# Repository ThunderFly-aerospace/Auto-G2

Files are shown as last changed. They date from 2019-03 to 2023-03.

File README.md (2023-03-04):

# Auto-G2 - Small gyroplane model
The design is based on [Auto-G2 by Durafly](https://hobbyking.com/en_us/duraflytm-auto-g2-gyrocopter-w-auto-start-system-821mm-pnf.html) which is extended by [PX4 autopilot](https://en.wikipedia.org/wiki/PX4_autopilot). The Auto-G2 model is discontinued and is not longer available. 
Adequate substitute is the [3D printed TF-G2 autogyro kit](https://github.com/ThunderFly-aerospace/TF-G2). 

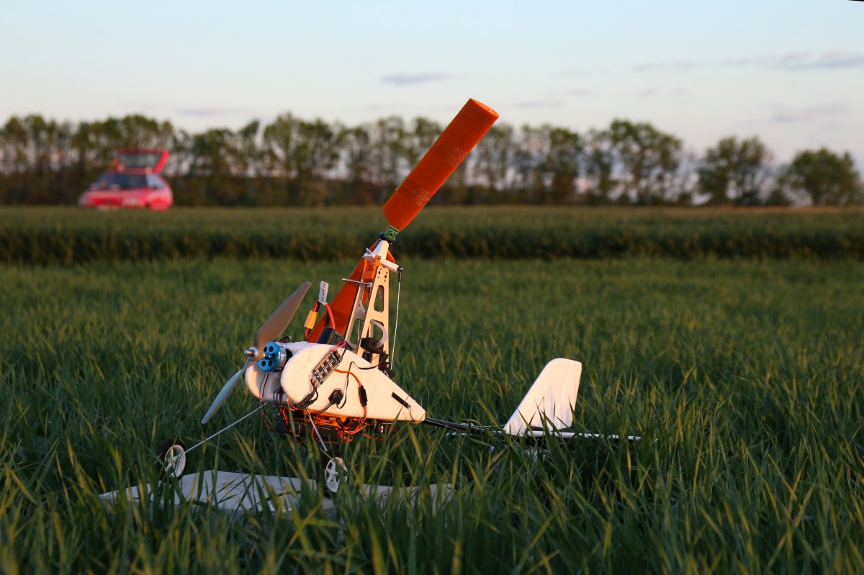
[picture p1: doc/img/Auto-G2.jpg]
Auto-G2 autogyro


The original purpose of this model is the training and testing of PX4 software improvements, prior the autogyro airframe has been sucessfully merged to [PX4 airframes](https://docs.px4.io/main/en/airframes/airframe_reference.html#autogyro).

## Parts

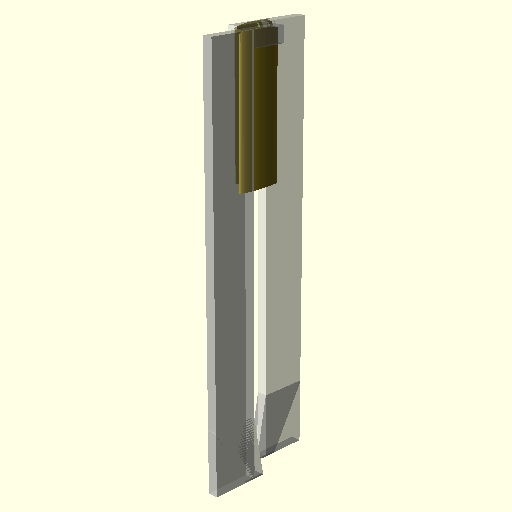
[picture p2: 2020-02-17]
CAD/img/print_plate_111_1009_parts_tips.png

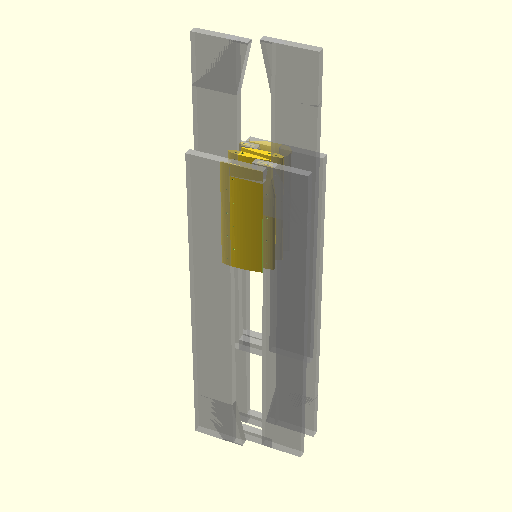
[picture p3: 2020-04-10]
CAD/img/print_plate_111_1009_parts.png

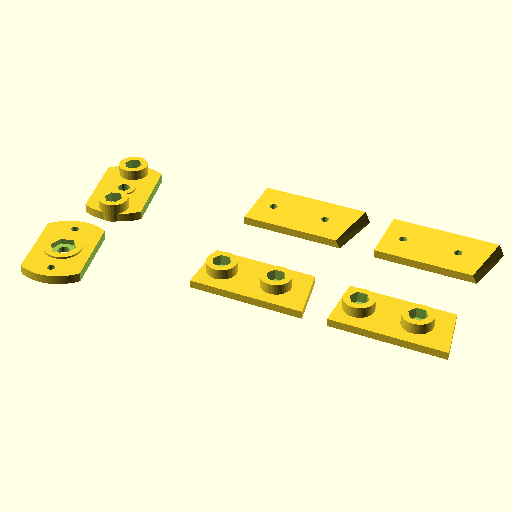
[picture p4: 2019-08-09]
doc/img/print_plate_rotor_parts.png

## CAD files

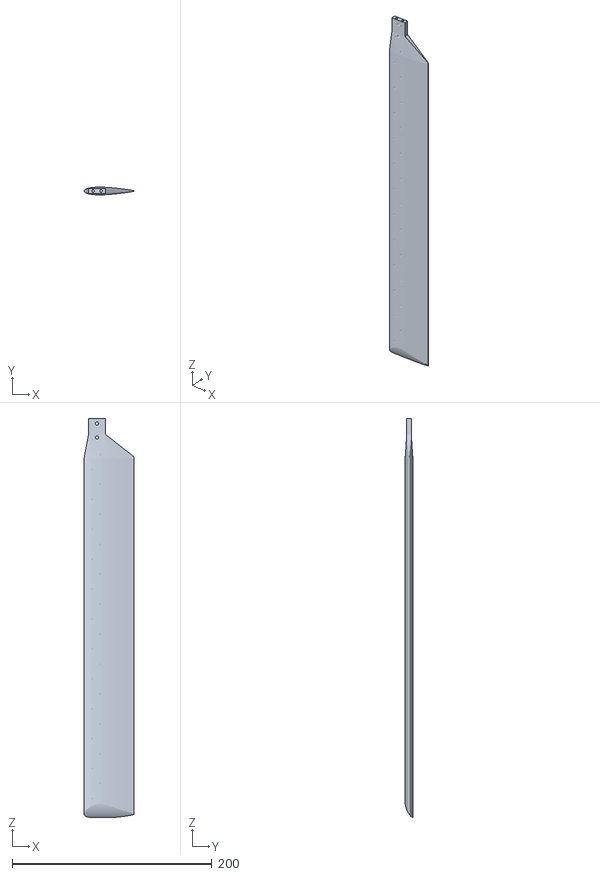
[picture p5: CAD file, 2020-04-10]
CAD/stl/111_1009.stl
50.0 x 7.80 x 400.0

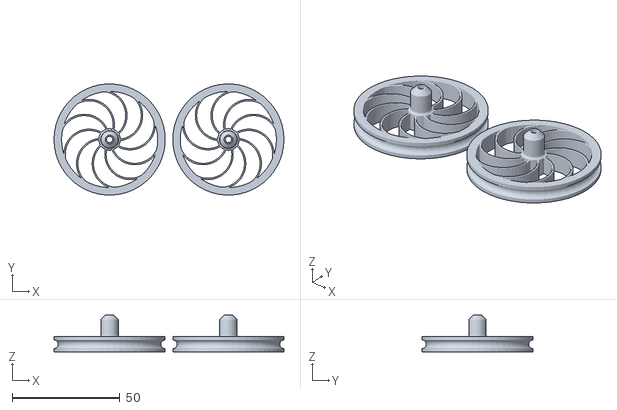
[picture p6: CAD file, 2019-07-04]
CAD/stl/manufacturing_helpers/print_plate_888_1011.stl
106.5 x 51.4 x 17.0

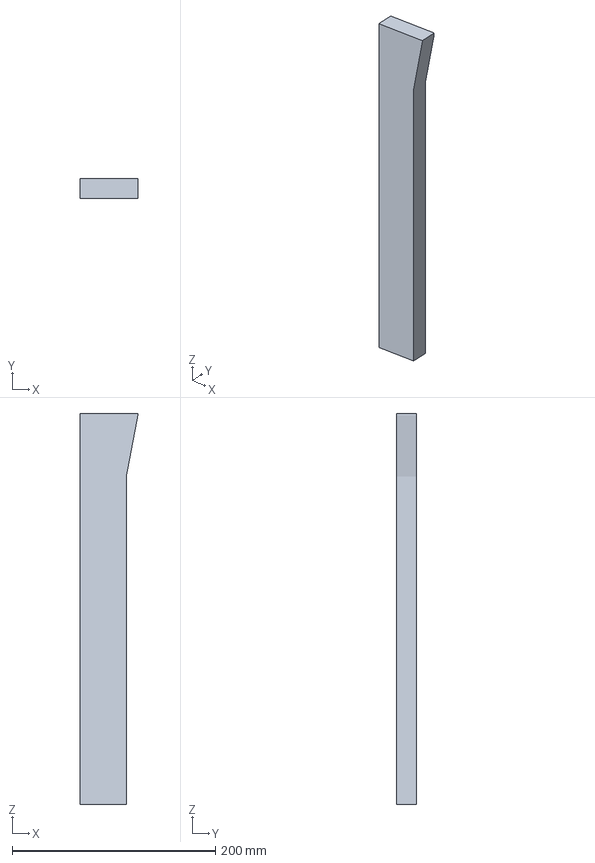
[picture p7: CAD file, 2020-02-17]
CAD/amf/111_1009_111_1009_modificator.amf
56.9 x 20.0 x 385.0 mm

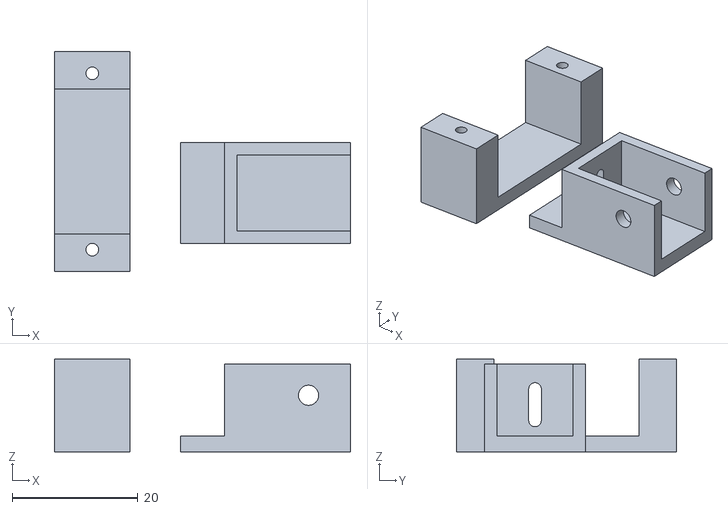
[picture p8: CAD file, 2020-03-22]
CAD/stl/888_1010.stl
47.0 x 35.0 x 14.8

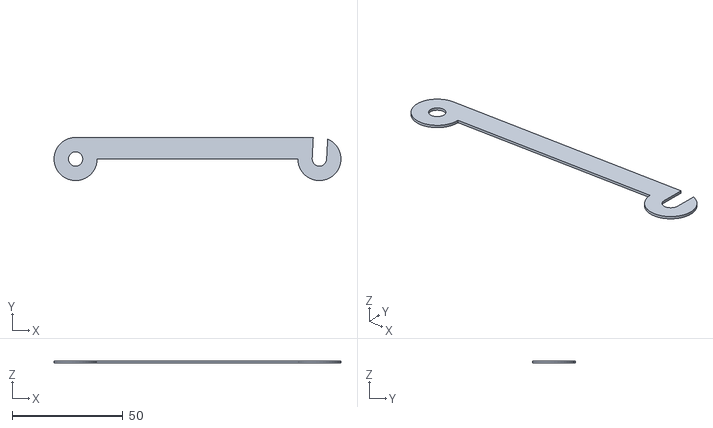
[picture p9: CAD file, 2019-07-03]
CAD/stl/manufacturing_helpers/print_plate_888_1009_scale.stl
129.5 x 19.5 x 1.00

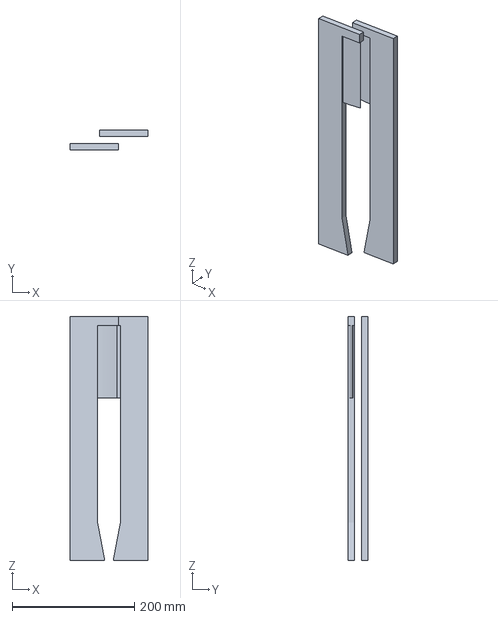
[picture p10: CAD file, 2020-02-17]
CAD/amf/print_plate_111_1009_parts_tips.amf
128.2 x 32.0 x 400.0 mm

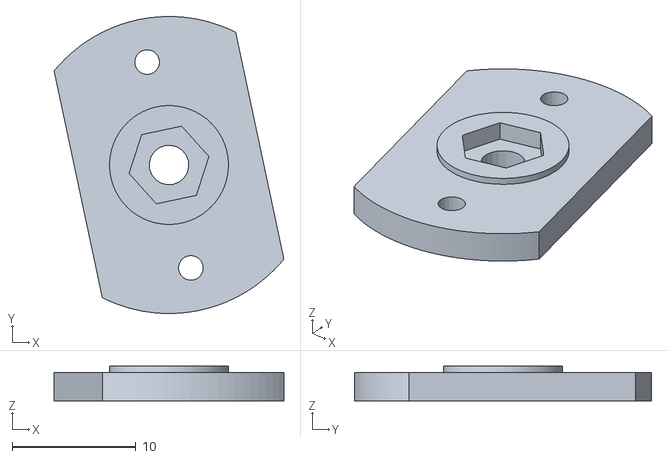
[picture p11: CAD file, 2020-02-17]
CAD/stl/111_1004.stl
18.6 x 24.0 x 2.80

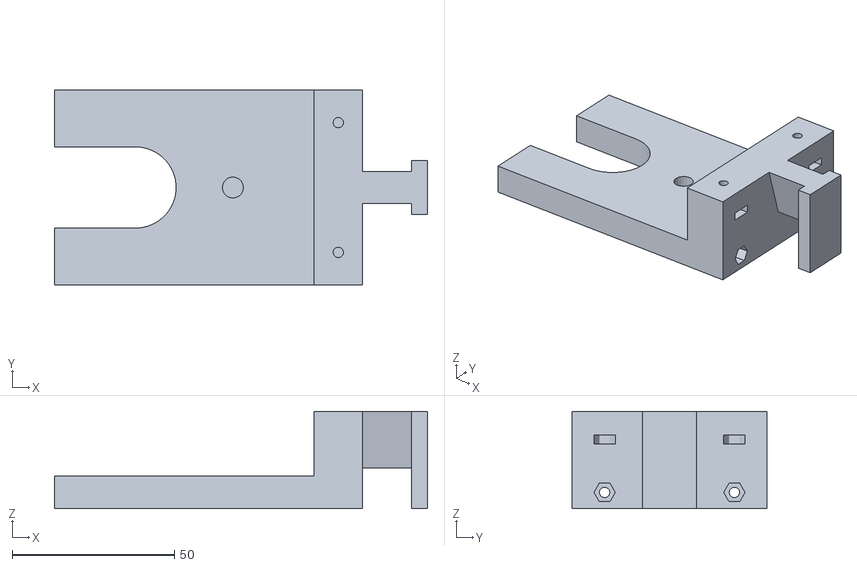
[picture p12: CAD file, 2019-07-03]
CAD/stl/manufacturing_helpers/print_plate_888_1009_cradle.stl
115.0 x 60.0 x 30.0

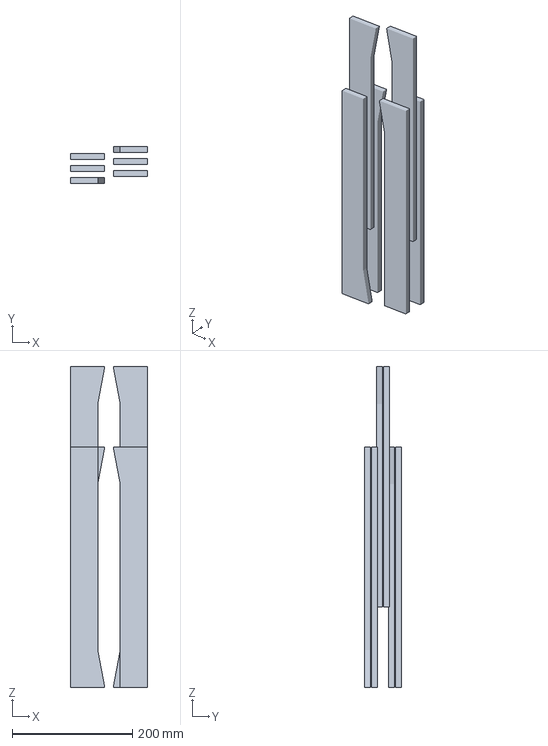
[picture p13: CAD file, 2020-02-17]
CAD/amf/print_plate_111_1009_parts_modificator.amf
128.2 x 62.0 x 533.3 mm

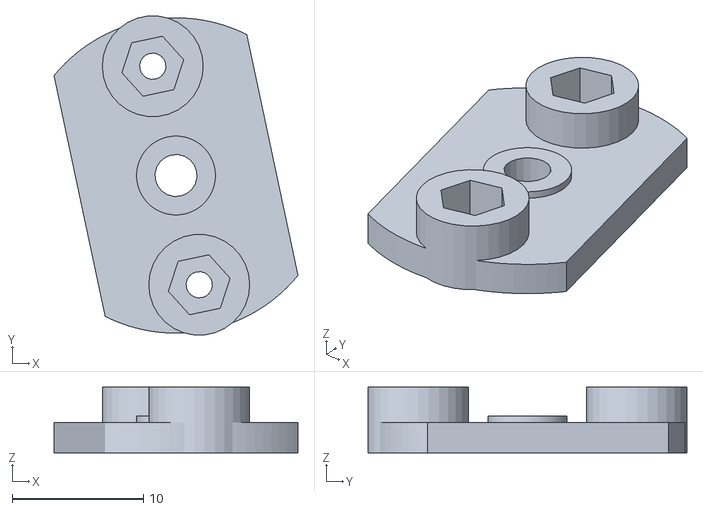
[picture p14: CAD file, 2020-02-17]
CAD/stl/111_1008.stl
18.6 x 24.3 x 5.00

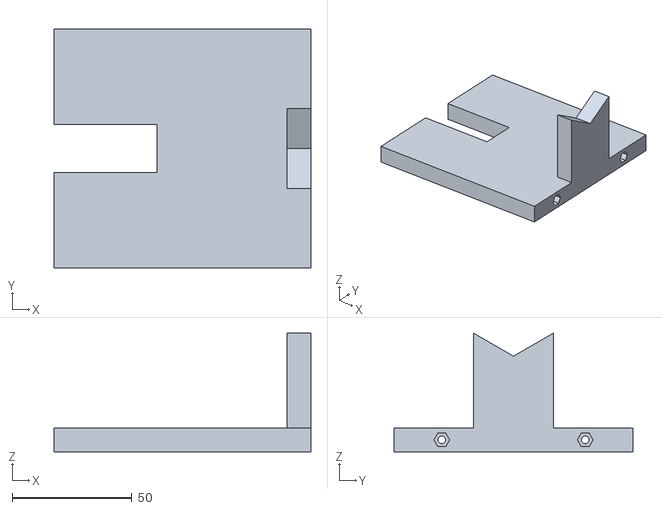
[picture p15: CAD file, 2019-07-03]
CAD/stl/manufacturing_helpers/print_plate_888_1009_base.stl
107.5 x 100.0 x 49.6

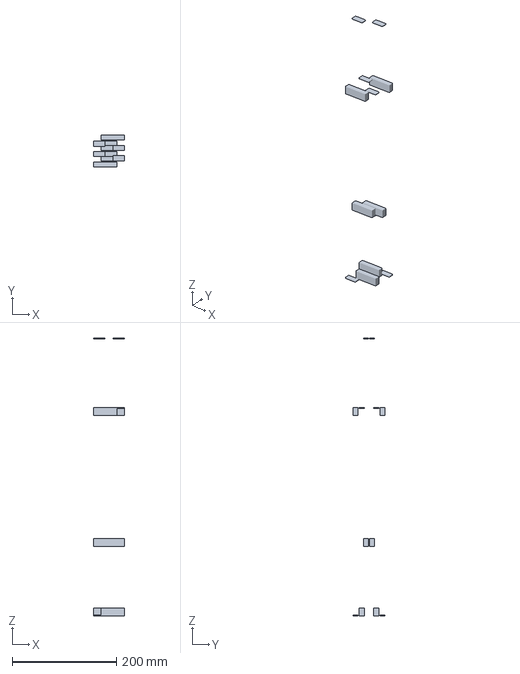
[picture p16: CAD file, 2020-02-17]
CAD/amf/print_plate_111_1009_parts_modificatorb.amf
60.0 x 62.0 x 533.3 mm

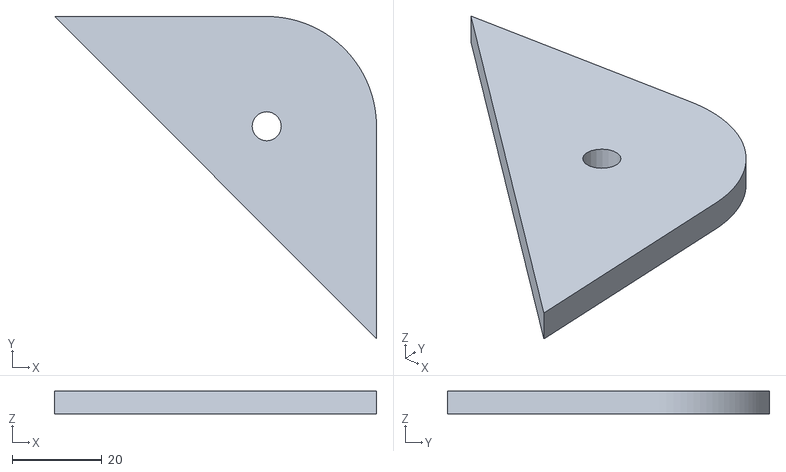
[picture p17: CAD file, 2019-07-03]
CAD/stl/manufacturing_helpers/print_plate_888_1009_shapeA.stl
71.8 x 71.8 x 5.10

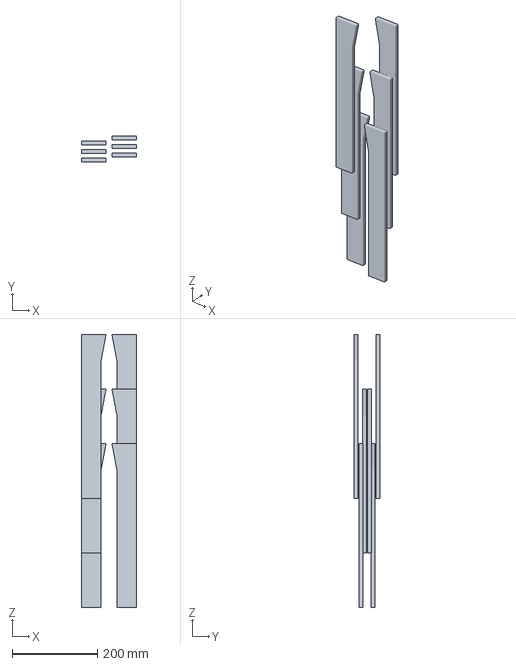
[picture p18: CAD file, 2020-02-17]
CAD/amf/print_plate_blades_parts_modificator.amf
128.2 x 62.0 x 641.7 mm

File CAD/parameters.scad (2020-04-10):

global_clearance = 0.5;
layer_thickness = 0.3;

//Main tube diameter - hole [mm]
main_tube_outer_diameter = 25.4;
main_tube_inner_diameter = 23.05;

// Nastavení parametrů rotoru

gliding_aggle = 14;         // tenhle úhel by se zřejmě v budoucnu měl počítat z požadované klouzavosti.

rotor_blade_AOA = 3.5;      // nastavení úhlu náběhu rotorového listu

// Rotor Auto-G2
rotor_blade_rod = true;  // generovat diru pro uhlikove tycky
rotor_blade_length = 400;   // délka rotorového listu
rotor_blade_depth = 52;     // hloubka rotorového listu
rotor_balde_tip_cutoff = 15; // delka sikme plochy na konci listu

blade_mount_length = 30;

blade_mount_width = 17;
blade_mount_thickness = 4.6;
blade_mount_screw_offset = 5; // distance of first screw from rotor end

// Testovaci maly rotor

        /*
        rotor_blade_rod = false;
        rotor_blade_length = 145;   // délka rotorového listu
        rotor_blade_depth = 45.5 * (145/385);     // hloubka rotorového listu
        blade_mount_length = 20;
        blade_mount_width = 10;
        blade_mount_thickness = 4;
        */

// konec parametru pro testovaci maly rotor

rotor_height = 180;         // výška otočného kloubu rotoru nad hlavní trubkou vírníku (odhad)
rotor_blades_count = 2;
rotor_delta_angle = 12;
rotor_blade_thickness = 5.1;

rotor_blade_naca = 0015;
//rotor_blade_naca = 1214;
rotor_blade_parts_count = 3;

blade_transition_length = 10; // length of blade transition

blade_mount_screw_distance = (16.47+11.86)/2;

/* blade_shell_thickness = 0.4;
blade_shell_thickness_inner = 0.4;
blade_shell_thickness_wire = 0.4;
blade_infill_distance = 25;
blade_infill_overlap = 0; */

/// Nastaveni pro Slic3r
blade_shell_thickness = 0.6;
blade_shell_thickness_inner = 0.13;
blade_shell_thickness_wire = 0.55;
blade_infill_distance = 30;
blade_infill_overlap = 0;


//blade_rod_position = [rotor_blade_depth/4 + 5, 0, 0];
//blade_rod_position2 = [rotor_blade_depth/4 - 5, 0, 0];

//blade_rod_position = [15, 0, 0];
//blade_rod_position2 = [4, 0.3, 0];

blade_rod1_diameter = 0.2;
blade_rod2_diameter = 2.58;
blade_rod3_diameter = 2.13;

blade_rod2_diameter = 2.58;
blade_rod3_diameter = 2.58;

blade_rod1_position = [3.65, 0, 0];
blade_rod2_position = [rotor_blade_depth/4 - 4, 0, 0];
blade_rod3_position = [rotor_blade_depth/4 + 4, 0, 0];

rod_from_end = 9;

rotor_head_width =  21.4;    //Rozměr 1 v nákresu
pilon_wall_thickness = 4.2;  // Rozměr 2 v nákresu
horizontal_screw_distance = 14.5;   // Rozměr 4 v nákresu
vertical_screw_distance = 12;       // rozměr 5 v nkresu
topscrew_distance_endofpilon = 5;

rotorhead_wall_thickness = 2; // sila tistenych dilu


bearing_outer_diameter = 10.2;    // Rozměr B1 v nákresu s přídavkem na toleranci otvoru
bearing_thickness = 4;        // Rozměr B2 v nákresu
//bearing_shaft_length = 19.5;    // Rozměr B3 v nákresu, Originalni hodnota 19.5
bearing_shaft_length = 20;    // Rozměr B3 v nákresu


// nastavení parametrů motoru

engine_angle = -8;
engine_diameter = 55;
engine_offset = 55;

engine_screws_radius = 15;
engine_holes_radius = (24 + 44)/4;
engine_shatf_hole_diameter = 13;

// screw length step - minimum difference in length between two types of screws
basic_screw_length = 5;

//Screw diameter and nut for M6 [mm]
M6_screw_diameter=6.5;
M6_head_diameter = 10+0.5;
M6_head_height = 6;
M6_nut_height = 4.9;
M6_nut_diameter = 11.8;
M6_nut_pocket = 10.4;

//Screw diameter and nut for M5 [mm]
M5_screw_diameter=5.5;
M5_head_height = 5;
M5_head_diameter = 13+0.5;
M5_nut_height = 4.5;
M5_nut_diameter = 9.4;
M5_nut_pocket = 8.4;

//Screw diameter and nut for M4 [mm]
M4_screw_diameter=4.5;
M4_screw_head_height = 4;
M4_nut_height = 3.2;
M4_nut_diameter = 8.4;
M4_nut_pocket = 7.5;

//Screw diameter and nut for M3 [mm]
M3_screw_diameter = 3.2;
M3_nut_height = 2.7;
M3_nut_diameter = 6.6;
M3_screw_head_height = 3;
M3_nut_pocket = 5.6;


//Screw diameter and nut for M2,5 [mm]
M2_5_screw_diameter = 2.7;
M2_5_nut_height = 2.3;
M2_5_nut_diameter = 6;
M2_5_nut_pocket = 5.1;

//Screw diameter and nut for M2 [mm]
M2_screw_diameter = 2.0;
M2_nut_height = 1.8;
M2_nut_diameter = 4.8;
M2_nut_pocket = 3.95;


blade_mount_screw = M3_screw_diameter;
blade_mount_nut = M3_nut_diameter;


//šroub servo
Servo_screw = 1.5;
Servo_nut_height = 1;
Servo_nut_diameter = 2.7;



//center_of_gravity_position = [main_pilon_position - tan(gliding_aggle)*rotor_height, 0, 0];


////podzvozek

radius_undercarriage = 25;
vzdalenost_x = tan(20) * 131;
vzdalenost_y = (131 - radius_undercarriage)/tan(79);
uhel_y = 90 - 20;
uhel_x = 90 - 79;

maximum_printable_size = 150;


////Pitotova trubice
Pitot_tube_diameter = 4.02 + 1;
Distance_hole_from_tube = 11.92;  //vzdálenost otvoru pro připevnění od samotné trubičky


////Vlečné zařízení
tow_ring_diameter = 20;
tow_ring_thickness = 5;
tow_ring_groove = 2;
tow_ring_hole_diameter = M3_screw_diameter;

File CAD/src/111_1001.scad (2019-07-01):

//// ThunderFly Auto-G2 Rotor Head - Part 1

/// Main parameters

include <../parameters.scad>

L1 = rotor_head_width;  // Length of the middle part
T1 = rotorhead_wall_thickness;  // Thickness of the middle wall
T2 = rotorhead_wall_thickness;  // Thickness of the side walls
H = 23;  // Hight of the part
L2 = 28;  // Length of the side walls

/// Parameters for holes
RC = M3_screw_diameter/2;  // Radius of the center screw holes
RP = M2_screw_diameter/2;  // Radius of the periphery screw holes
DY = horizontal_screw_distance;  // Y-axis distance of the periphery screw holes
DZ = vertical_screw_distance;  // Z-axis distance of the periphery screw holes

shift =  - 15;
CHT = [0, shift, -20];  // Center hole translation

fn = 100;  // default face number for cylinders
/// Main object

module body() {
    translate([0,-T1/2, 0]) difference() {
        union(){
            translate([0, 0, 0])
                cube([L1, L2, H], center= true);
            hull(){
                translate([0, -L2/4, -vertical_screw_distance/2 - topscrew_distance_endofpilon])
                    cube([L1, L2/2, 0.1], center= true);
                translate(CHT+[0, T1/2, 0])
                    rotate([0,90,0])
                        cylinder(r=RC+2, h=L1+4, center = true, $fn=fn);

            }


            hull(){
                translate([0, 0, 0])
                    cube([L1, L2, H-6], center= true);
                translate(CHT+[0, 6, 7])
                    rotate([0,90,0])
                        cylinder(r=RC+2, h=L1, center = true, $fn=fn);

            }

        }

        cube([L1-2*T2, L2-2*T1, H*10], center = true);

        translate([0,0,-50])
            cube([L1-2*T2, 50, 100], center = true);
    }

}



/// Part 1 with holes and incisions
module Part1(){
    translate(-CHT){
        difference(){
        body();
           // Screw holes
            translate(CHT) rotate([0,90,0]) cylinder(r=RC, h=L1+10, center = true, $fn=fn);
            rotate([0,90,0]) translate([DZ/2,DY/2,0]) cylinder(r=RP, h=L1+2, center = true, $fn=fn);
            rotate([0,90,0]) translate([-DZ/2,DY/2,0]) cylinder(r=RP, h=L1+2, center = true, $fn=fn);
            rotate([0,90,0]) translate([DZ/2,-DY/2,0]) cylinder(r=RP, h=L1+2, center = true, $fn=fn);
            rotate([0,90,0]) translate([-DZ/2,-DY/2,0]) cylinder(r=RP, h=L1+2, center = true, $fn=fn);

           // Zapusteni pro matky
            rotate([0,90,0]) translate([DZ/2,DY/2,0]) cylinder(d=M2_nut_diameter, h=L1-2*T2+1, center = true, $fn=6);
            rotate([0,90,0]) translate([-DZ/2,DY/2,0]) cylinder(d=M2_nut_diameter, h=L1-2*T2+1, center = true, $fn=6);
            rotate([0,90,0]) translate([DZ/2,-DY/2,0]) cylinder(d=M2_nut_diameter, h=L1-2*T2+1, center = true, $fn=6);
            rotate([0,90,0]) translate([-DZ/2,-DY/2,0]) cylinder(d=M2_nut_diameter, h=L1-2*T2+1, center = true, $fn=6);
        }
    }
}

Part1();

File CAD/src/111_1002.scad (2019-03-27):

//// ThunderFly - Rotor Head - Part 2

include <../parameters.scad>

length = rotor_head_width-2*rotorhead_wall_thickness-0.15; // Length of the part
axis_diameter = M3_screw_diameter;
space = 1; // Axis hole distance
wall = 1;

add = 5; // prodlouzeni osy ve smeru roll osy

$fn = 100;

module Part2(){
  translate([0, 0, -wall-axis_diameter/2])
    difference(){
        hull(){
            translate([-length/2, -(axis_diameter + 2*wall)/2, 0])
                cube([length, axis_diameter + 2*wall, axis_diameter + 2*wall + add]);
            translate([0, axis_diameter + space, 0])
                cylinder(d = axis_diameter + 2*wall, h = axis_diameter + 2*wall + add);
        }
    translate([0, axis_diameter + space, -0.1])
        cylinder(d = axis_diameter, h = 100);
    rotate([0, 90, 0])
        translate([-(axis_diameter + 2*wall)/2, 0, -50])
            cylinder(h = 100, d = axis_diameter);
    }
}

Part2();

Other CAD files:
CAD/amf/print_plate_rotor_parts.stl
CAD/stl/print_plate_888_1011.stl
CAD/stl/manufacturing_helpers/print_plate_888_1009_shapeB.stl
CAD/stl/print_plate_888_1001.stl
CAD/src/111_1003.scad
CAD/STL/111_1009_parts.stl
CAD/STL/111_1102.stl
CAD/amf/111_1002.amf
CAD/amf/111_1009.amf
CAD/amf/888_1010.amf
CAD/amf/print_plate_rotor_parts.amf
CAD/src/111_1004.scad
CAD/src/111_1005.scad
CAD/src/111_1006.scad
CAD/src/111_1007.scad
CAD/src/111_1008.scad
CAD/src/111_1009.scad
CAD/src/111_1101.scad
CAD/src/111_1102.scad
CAD/src/4printing/print_plate_111_1009_parts.scad
CAD/src/4printing/print_plate_111_1009_parts_tips.scad
CAD/src/4printing/print_plate_888_1001.scad
CAD/src/4printing/print_plate_888_1011.scad
CAD/src/4printing/print_plate_rotor_parts.scad
CAD/src/888_1001.scad
CAD/src/888_1002.scad
CAD/src/888_1003.scad
CAD/src/888_1010.scad
CAD/src/888_1011.scad
CAD/stl/111_1001.stl
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

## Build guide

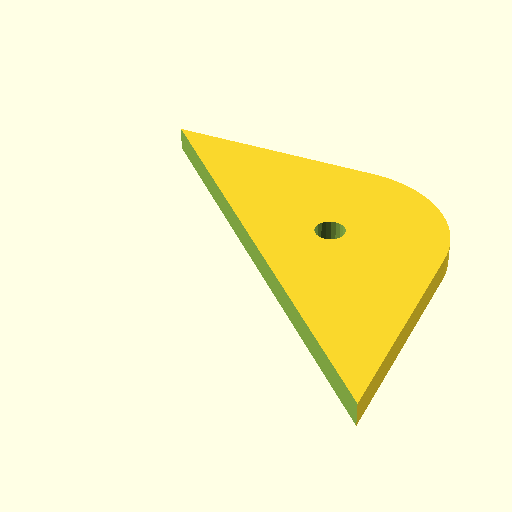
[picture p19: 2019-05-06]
doc/img/print_plate_1009_shapeA.png

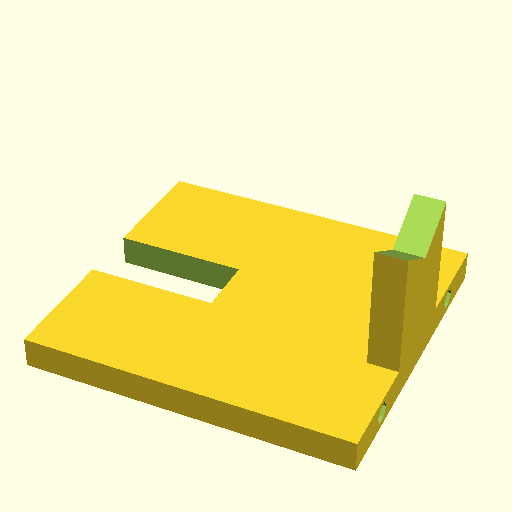
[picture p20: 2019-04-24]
doc/img/print_plate_1009_base.png

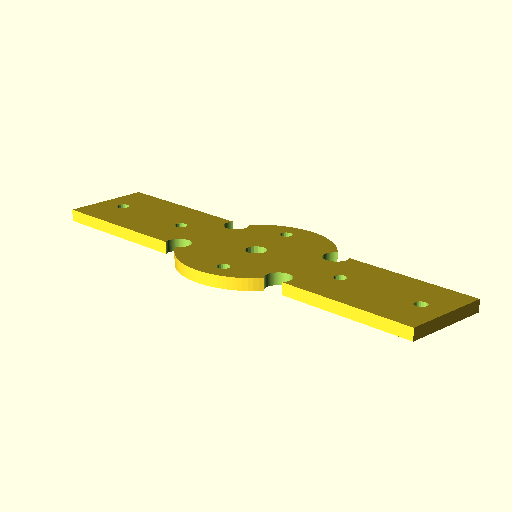
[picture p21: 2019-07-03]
doc/img/print_plate_888_1001_4.png

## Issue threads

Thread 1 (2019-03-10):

Rotorová hlava umožňující řízení roll i pitch os

roman-dvorak, 2019-03-10:
Je potřeba namodelovat rotorová hlava pro Auto-G2 napodobující fungování rotorové hlavy vírníku TF-G1.

Rotorová hlava musí umožňovat změnu výchylek v osách pitch a roll.

Modely je potřeba modelovat parametricky, aby bylo možné snadno změnit jejich rozměry. Rozměry, které jsou napsané tužkou jsou jen odhadnuté. @kaklik je přeměří a upřesní.

Na tomto obrázku je vidět, kde tyto modely budou umístěny. Půjde o nahrazení originálních dílů umístěných přímo pod rotorem.

## Díl 1
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

První díl slouží k udržení konstantní vzdálenosti dvou dřevěných postranních částí pilonu a zároveň je v něm umístěna osa okolo které se otáčí ```Díl 2```. Tento díl je k postranním deskám přidělán pomocí dvou čtveřic šroubků.

## Díl 2
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

Tento díl má být taková spojka pro 2 osy, které půjdou kolmo proti sobě. Zároveň tento díl má sloužit k centrování vrchní osy.

## Díl 3
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

Třetí díl se oproti dílu ```Díl 2``` chová jako kloub v ose roll (náklon rotoru do stran). Kloub bude vytvořen M3 DIN912 šroubem, který musí mít v tomto dílu zapušťěnou hlavu.

Délka a šířka tohoto celého dílu není rozhodující. Podstatná je délka "tunelu" pro osu rotoru. Tyto rozměry zatím budou upřesněny. Pro první návrh je jeho délka cca 20mm. Osou je M3 šroub. Na každém konci je ložisko, které musí být v tomto "tunelu" zapuštěno.

Z každé strany tohoto dílu budou vyčnívat takové šikmé (rozbíhající se) sloupky.. Sloupky můžou začínat podstatně blíže středu tohoto dílu (než je na obrázku). Tím lze dosáhnout menšího dílu.

roman-dvorak, 2019-03-13:
Mathieu Bresciani z Auterionu nám změřil potřebné rozměry.

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

1 - 21.4mm (where your drawing shows the arrow) and 26.3mm (where it's attached to the aircraft)
2 - 4.2mm
3 - 2.5mm with a screw for plastic that has a thread length of 9mm
4 - 14.5mm
5 - 12.0mm

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

B1 - 7mm
B2 - I wasn't able to remove the bearing, but it's at least 3mm
B3 - 19.5mm

kaklik, 2019-03-13:
Super :)  Přidal jsem [soubor](https://github.com/ThunderFly-aerospace/Auto-G2/blob/master/CAD/parameters.scad), do kterého jsem tyto parametry přepsal pro přímé použití v openscadu. Navíc tam jsou přidané i další tiskové parametry vyzkoušené na modelu TF-G1.

kaklik, 2019-03-14:
Určitě bude  lepší, když všechny osy rotace budou ležet pokud možno v jedné rovině. Bylo by pak úplně nejlepší kdyby páky po táhla mohly být v úrovni osy pro pohyb roll.

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

Otvory pro šrouby, které použijeme jsou u kulových čepů M2. Možná maximálně M2.5.
Taktéž i šrouby pro přichycení k překližkovým bočnicím budou M2.

Myslím že aktuálně nakreslená hlava je podstatně vyšší, než je současná délka bowdenu od prerotátoru. bylo by tak zřejmě vhodné pouzdro pro ložiska rotoro posunout dolu a třeba jej rozdělit na dvě části. Pod osou šroubu osy roll a nad ní.

Při skládání se stejně nejdříve přišouroubuje šroub Roll a pak se prostrčí osa rotoru pouzdrem.

roman-dvorak, 2019-03-15:
Ano, otvory k přidělání k dřevěným nosníkům mají zmenšené díry na M2

Táhlo je v ose šroubů. (roll kloubu)

Ložiskové pouzdo je posunuto o kus níže.

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

roman-dvorak, 2019-03-17:
Potřebné úpravy:

- Zmenšit tolerance okolo os (šroubů)
- Rozšířit díl 111_1002
- Prodloužit rameno dílu a zároveň to to rozšířit do stran (vnější vzdálenost 65). 111_1003..
- Díru pro osu (díl 111_1001) posunout více dopředu.

kaklik, 2019-03-18:
Úchyty pro kulové klouby by zřejmě bylo lepší upravit tak, aby matice šroubu uchycujícího kloub byla zapuštěna v šestihranném otvoru z vnitřní strany páky pro táhlo.
Při rozebírání tak matice bude z páky méně vypadávat.

kaklik, 2019-03-26:
Hodilo by se zkontrolovat, jestli rozměry hlavy odpovídají tomuto nákresu:

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

V případě úprav spodního dílu se čtyřmy šrouby pro uchycení hlavy by bylo vhodné matice těchto šroubů zapustit do stěny. Výrazně by to usnadnilo montáž.

kaklik, 2019-04-03:
Vzdálenost mezi ložisky rotorové hlavy upravit tak, aby vycházela na  délku části šroubu bez závitu. Závit by měl končit tak, že při dotažení maticí by měla mezi šroubem a ložiskem zůstat minimální vůle.  Délka dříku šroubu je 20mm.

Zároveň by pouzdro pro ložiska asi nemuselo být až tak masivní. Je výhodné, aby se při havárii utrhl celý rotor i s ložisky. Možná se tím ochrání serva a zbylé části pilonu.

kaklik, 2019-04-03:
Vzdálenost mezi ložisky rotorové hlavy upravit tak, aby vycházela na  délku části šroubu bez závitu. Závit by měl končit tak, že při dotažení maticí by měla mezi šroubem a ložiskem zůstat minimální vůle.  Délka dříku šroubu je 20mm.

Zároveň by pouzdro pro ložiska asi nemuselo být až tak masivní. Je výhodné, aby se při havárii utrhl celý rotor i s ložisky. Možná se tím ochrání serva a zbylé části pilonu.

kaklik, 2019-04-09:
Spodní díl rotorové hlavy by bylo vhodné diagonálně vystužit tak, aby se zvýšila jeho tuhost.
A nemohlo se stát tohle:
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

Closed 2019-04-11.

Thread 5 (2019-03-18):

Tolerance dílů pro uchycení rotorových listů

kaklik, 2019-03-18:
Tištěné díly pro polohování rotorových listů zřejmě nemají zavedené tolerance, které  by řešily nepřesnost tisku.

Closed 2019-03-20.

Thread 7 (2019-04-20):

Vyvažovací přípravek na listy

kaklik, 2019-04-20:
Pro vyvažování listů by bylo potřeba upravit [Vyvažovací přípravek](https://github.com/ThunderFly-aerospace/TF-G1/blob/master/src/manufacturing_helpers/888_1009.scad) z vírníku TF-G1.

Potřebné změny jsou následující:

- [x] Upravit trojúhelníky pro uchycení listů tak, aby do přípravku bylo možné upnout i list vírníku Auto-G2
- [x] Upravit rozměr tak, aby střed otáčení kolébky byl uprostřed tloušťky listu
- [x] Zmenšit hmotnost tištěného dílu pohyblivé kolébky za účelem zvětšení citlivosti vyvážení.
- [x] Pokud je to možné tak pohyblivý díl zmenšit na tištěný rozměr 150mm, aby bylo možné kolébku vytisknout v kuse

kaklik, 2019-04-21:
Vidím, že zřejmě není zmeněná předpokládaná tlouška listu. Ta je u testovacích listů 5.1mm.

Closed 2019-04-25.

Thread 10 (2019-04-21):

Testovací přípravek na měření charakteristik rotoru

kaklik, 2019-04-21:
Pro měření rotoru by bylo potřeba vytvořit nové díly vycházející ze současné konstrukce rotorové hlavy. Tak aby bylo umožněno rotor naklonit pod definovaným úhlem dozadu a měřit jeho vztlak a odpor. Náklon rotoru do stran není třeba uvažovat. Důležitá je fixace náklonu v nastavitelném úhlu v rozsahu 0° (vodorovně) až -30° (sklon dozadu).

kaklik, 2019-04-29:
Na měřící variantě rotorové hlavy by ještě byl potřeba snímač otáček rotoru. Ten může být buď optický, nebo magnetický.

kaklik, 2019-05-01:
Způsob nastavení úhlu rotoru bude vyřešen takto:

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

Na jedné straně bude hlava šroubu uchycena do[ kluzného přírubového ložiska](https://www.igus.eu/product/372) s průměrem otvoru 8mm.
Na druhé straně (v pohyblivé části rotoru), bude šroub uchycen dvojicí čtvercových matic M6 na kyvném dílu.

kaklik, 2019-05-21:
Vytvořil jsem díl, ze kterého by mohl vycházet držák rotoru.
https://github.com/ThunderFly-aerospace/Auto-G2/blob/master/CAD/src/888_1003.scad

Původně byl zamýšlen pro ruční testy. Nyní může být zmodifikován na šrobovatelný držák, protože přišroubovatelný držák stejně jde použít i na ruční testy.

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

Closed 2019-06-06.

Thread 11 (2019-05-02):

Tisknutelná varianta rotorových listů

kaklik, 2019-05-02:
Vytvořit model tisknutelných listů.  Model listu by měl zachovávat stávající způsob montáže s tím, že výhledové může být jeden z dvojice šroubů nahrazen za střižný element.

Výztuha listu může být realizována z uhlíkové kulatiny o průměru 1-2 mm.  Předpokládaný profil listu je [Clark Y](http://airfoiltools.com/airfoil/details?airfoil=clarky-il).

Nejproblematičtější částí konstrukce modelu listu je tvorba tištěné výztuhy. Zde je nejdále [3dlabprint](https://3dlabprint.com/). Kde jejich metoda generování výztuh je neznámá. Nicméně určitou variantu metody popisuje [toto video](https://www.youtube.com/watch?v=ENtC-d1bXdM).

roman-dvorak, 2019-05-08:
- [ ] Zkrátit délku listů - délka v parametrech je délka včetně závěsu rotoru
- [ ] Zámky pro správné sesazení se setkávají s trubičkou.
- [ ] Zmenšit rozlišení profilu listu - na cca 150
- [ ] Změnit podélné vyvážení rotoru. tenčí odtoková hrana.

kaklik, 2019-05-12:
Při dělení listů na tiskové díly by zřejmě bylo dobré je dělit tak, aby výsledné části byly pokud možno stejně dlouhé. Optimalizuje se tím doba tisku.

kaklik, 2019-08-19:
Je potíž s tiskem tenkých stěn. Navíc model obsahuje v místech dělení některé artefakty žeber a vzájemného spojení listů.

roman-dvorak, 2019-08-27:
Do modelu je potřeba namodelovat nové, výstuhy, které budou vyztuhovat jednotlivé dráty a plášť. Vytvořit hustější infill v okolí kořenu listu.

Dále by bylo vhodné v modelu mít pár otvorů pro vpravení lepidla v průběhu dílu.

kaklik, 2019-10-02:
Poslední vytištěné kusy vykazují značnou nekonzistenci tvaru odtokové hrany.

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

Zřejmě je potřeba, aby model neměl odtokovou hranu až do nulové tloušťky, ale končil třeba na tloušťce 0,4-0,6mm což by mělo odpovídat minimální šířce extruze.

Dále by bylo vhodné, aby přídavná žebra v náběžné hraně dosahovala až i třetí uhlíkové tyčky a nokončila před ní.

roman-dvorak, 2019-10-02:
Když máme tyto relativně funkční listy (hlavně známe správnou polohu závaží, tak navrhuji to přepracovat do té varianty tenkých stěn. Resp. plně vyplněného listu s mezerami tvořící infill.

Asi by pro to bylo vhodné založit nové issue a detailněji to popsat. To by totiž mohl být docela pokrok v tisku a jejich kvalitě

kaklik, 2020-01-28:
Taktéž by asi bylo vhodné zkusit použít symetrický profil.  Je pravděpodobné, že by to vedlo ke snížení intenzity vibrací.

kaklik, 2020-02-17:
Aktuálně vytištěné modely mají tyto vady:

- [ ] Těžko se odstraňuje brim - lepší by bylo listy připevnit k podložce materiálem, který zůstane součástí listu.
- [ ] Špatně se zarovnávají tyčky do konce listu, neboť konec listu je úplně průchozí. Zde by se hodil jen malý otvor na odvzdušnění při dávkování lepidla
- [ ] Lepidlo se špatně dostává do otvorů pro tyčky, zde by bylo asi vhodné, kdyby tištěná trubička měla nějaký buď oválný tvar a nebo zde byly odvzdušňovací otvory skrz které se vymáčkne vzduch při dávkování lepidla.

kaklik, 2020-02-25:
Na vyrobených listech jsou tyto nové problémy:
- Zakončení otvoru pro vyztužovací drát lze snadno prorazit
- Lepidlo se stále velmi špatně nanáší na nosníky. Problematické je to zejména v kořenové části.

V případě kořenové části by zřejmě bylo vhodné, aby list byl půlený a byla tak větší kontrola nad nanesením lepidla na celou plochu nosníku.

Closed 2020-07-03.

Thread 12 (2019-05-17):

Vyvážení rotorových listů

kaklik, 2019-05-17:
Je potřeba, aby těžiště listu bylo v 25% hloubky listu. Tím bude minimalizováno kroucení listu v průběhu otáčky.

Tisknutelné rotorové listy by zřejmě bylo vhodné překonstruovat tak, aby v náběžné hraně bylo wolframové válcové závaží, pak hlouběji v listu mosazný drát fungující jako nosník a částečně jako závaží.  Symetricky oprotiti těžišti musí být výztuha naopak s malou hmotností, nejspíše uhlíková.

kaklik, 2019-06-18:
- Prvním výsledkem výpočtu má být zjištění, zda je možné list vyvážit za použití pouze mosazných závaží.  A nebo je potřeba použít hustší materiál například [wolfrmamové elektrody](https://svareci-technika-breclav.cz/eshop/prislusenstvi-stroju/tig2012-11-05-09-28-30_/spotrebni-dily2012-11-05-09-28-59_/wolframova-elektroda-zelena-detail).
- Dále je pak potřeba zjistit optimální geometrické rozložení závaží a jejich průměry
- Následně je podle toho potřeba upravit model z issue #11

roman-dvorak, 2019-06-22:
Napsal jsem stručný návod, jak počítat celkové těžiště rotorového listu.
[Wiki: Vyvážení rotorových listů](https://github.com/ThunderFly-aerospace/Auto-G2/wiki/Vyv%C3%A1%C5%BEen%C3%AD-rotorov%C3%BDch-list%C5%AF)

roman-dvorak, 2019-06-27:
Zjistlil jsem, že v modelu rotorového listu byla chyba, která způsobovala vždy konstantní tloušťku (1 mm) vnějšího pláště a parametr, který k nastavení této hodnoty má sloužit nefungovat. Tento problém jsem opravil. A je tedy možné, že když bude stěna listu tenčí, že bude možné použít pouze jeden mosazný drát nebo dva umístěné okolo osy závěsu.

Je však třeba toto ověřit výpočtem těžišt.

kaklik, 2019-08-27:
Současná poloha těžiště od náběžné hrany listu je 11,47 mm. což je pro aktuální použití dostatečné.

Closed 2019-08-27.

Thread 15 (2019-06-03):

Vypouštěcí zařízení pro vírník TF:Auto-g2 z lana

roman-dvorak, 2019-06-03:
Protože se start z lana osvědčil jak s vírníkem TF:Auto-G2 tak i s vírníkum TF-G1, tak je potřeba nakreslit vypouštěcí zařízení pro start.

Zařízení by mělo vypadat nějak takto:
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

Bude to taková "kostka", skrze kterou bude prostrčen M3 šroub (nebo jiná osa). V zadní části bude přiděláno servo, který bude vytahovat ocelový drát zajišťující lano oproti ose (M3 šroubu).

V modelu musí jít nastavovat vzájemná poloha serva a hlavní kostky (ve dvou osách), kde bude docházet k odpojování lana. Dále musí jít nastavovat rozměr kostky, tloušťka stěn a spodni spojovací části. Výška sloupků a rozteče děr pro přidělání serva. Délka celého dílu by neměla přesáhnout cca 5 cm. Kostka může být dlouhá cca 2 cm,

alcamrkvicka, 2019-06-10:
Vypouštěcí zařízení ( 888_1010 ) je přesně podle zadání hotové.
Jen je potřeba případně upravit parametry serva a jeho držáku respektive sloupků k jeho držení.
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

roman-dvorak, 2019-06-10:
![Uploading 64297652_2460635970614821_3844892678005194752_n.jpg…]()

kaklik, 2019-06-10:
Držák je potřeba upravit tak, aby servo mělo u páky minimálně o polovinu více místa na výšku.

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

alcamrkvicka, 2019-06-11:
Výška sloupků zvětšena, jsou 2 možnosti: buď 1/2 nebo 2/3 výšky serva.
A taky jsem posunula celý držák  víc excentricky.
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

roman-dvorak, 2019-06-11:
@kaklik nechceme, aby to servo bylo ještě dál? Nebo to je takle OK? Protože předpokládám, že tam bude ještě nějaká ta koncovka táhla a ta má také alespoň 2 cm..

kaklik, 2019-06-11:
To taky trochu záleží na tom, jak to na ten vírník plánuješ namontovat. Ale myslím že to klidně může být celý delší.

roman-dvorak, 2019-06-12:
můj předpoklad je to nalepit tavným lepidlem zespodu.

roman-dvorak, 2019-06-17:
Vypouštěcí zařízení se jeví jako funkční. Bylo provedeno několik testů na zemi i odpoutání ve vzduchu. Rozsah serva byl omezen pomocí mixeru. Odpojovací zařízení bylo připojeno k AUX výstupu. Odpojovací kanál je namixován ze dvou přepínačů. Za letu je to velmi nepraktické, protože i jeden z nich je náročné obsluhovat. Možná by stálo za to zkusit jinou kombinaci vypínačů.

Při vypnutém přepínaci je zablokované roztočení motoru - resp. Výstup z vysílačky je nulový.

Předletový test odpojovacího zařízení  https://youtu.be/7BKLIAm5EnU

roman-dvorak, 2019-06-30:
Díry pro přidělání serva jsou daleko od sebe. Jejich vzdálenost má být 28 mm.

Z důvodů hmotnosti a menšího motoru (menší magnetické rušení) jsme chtěli dát jiné servo. Servo na sobě němělo celé drážky (jako původní servo) ale jen díry na šroub, které nesedí s dírou ve vypouštěcím zařízení. Servo bylo prozatím propilováno.

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

Také bych o trošku zesílil spodní stěnu. Např o 0.5 mm

roman-dvorak, 2019-07-21:
Díl by bylo vhodné rozdělit na 2 části. Na část se servem a část kostky s osičkou. Cílem toho je, aby bylo možné odebrat přední podvozek vírníku bez nutnosti se to snažit odlepit.

Closed 2019-08-18.

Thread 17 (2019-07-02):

Zlepšit možnost utržení listu

kaklik, 2019-07-02:
V [unašeči rotorových listů](https://github.com/ThunderFly-aerospace/Auto-G2/blob/master/CAD/STL/888_1001.stl) by bylo potřeba vytvořit zářezy z boku. Které definují místo, kde se list má ulomit při havárii.

Představuji si, že utržení listu by mělo proběhnout v místě napojení na středový kruh. Na obrázku vyznačeno červenou barvou.  Puntíky označují místa ztečení, které se dají vytvořit například odečtením válců.

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

alcamrkvicka, 2019-07-03:
Pochopila jsem to nejspis trochu jinak, ale taky by to mohlo fungovat, ne?
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

kaklik, 2019-07-03:
Jo to tohle je úplně správně. :)

Teď jen potřebujeme vytvořit sadu takových destiček s různě velkým vykousnutím. Protože zatím nevím, jak velké vykousnutí bude správně pevné.

kaklik, 2019-07-05:
Úprava pomohla a stačí i ten úplně nejmenší z řady otvorů. :)

Closed 2019-07-05.

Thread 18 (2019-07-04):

Potíže s renderováním modelu 888_1011.scad

kaklik, 2019-07-04:
Náboj tištěného kola zřejmě obsahuje strukturu, kterou nelze vyrenderovat.

```
&/CAD$ make -j4
openscad -m make -o STL/111_1008.stl src/111_1008.scad
openscad -m make -o STL/888_1011.stl src/888_1011.scad
openscad -m make -o STL/111_1003.stl src/111_1003.scad
openscad -m make -o STL/111_1009.stl src/111_1009.scad
ECHO: 10.4305
ECHO: "Tire cross-sectional diameter is 4"
ECHO: "Tire circumferential stretch is 1.01"
ECHO: "Tire (unstretched): [inner, center, outer]"
ECHO: "  * Diameter: 47, 51, 55"
ECHO: "  * Circumference: 147.65, 160.22, 172.79"
ECHO: "Tire Stretched: [inner, center, outer]"
ECHO: "  * Diameter: 47.51, 51.51, 55.51"
ECHO: "  * Circumference: 149.26, 161.82, 174.39"
ECHO: "Tire Knobbed: [outer]"
ECHO: "  * Diameter: 53.51"
ECHO: "  * Circumference: 168.11"
ECHO: "Wheel diameter will be 51.51"
ECHO: "Number of tires will be 2"
DEPRECATED: The assign() module will be removed in future releases. Use a regular assignment instead. in file 888_1011.scad, line 384
DEPRECATED: The assign() module will be removed in future releases. Use a regular assignment instead. in file 888_1011.scad, line 414
WARNING: Too many unnamed arguments supplied, in file 888_1011.scad, line 430
ECHO: "Spiral Style..."
DEPRECATED: Using ranges of the form [begin:end] with begin value greater than the end value is deprecated.
WARNING: Problem converting rotate(a=[0, 0, -inf]) parameter, in file 888_1011.scad, line 983
WARNING: Problem converting rotate(a=[0, 0, nan]) parameter, in file 888_1011.scad, line 983
stlsort STL/111_1008.stl || :
openscad -m make -o STL/111_1002.stl src/111_1002.scad

```

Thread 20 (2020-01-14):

Autogyro airframe pull-request

kaklik, 2020-01-14:
The Auto-G2 airframe is tested enough to make a new autogyro airframe pull-request from it.

This should finish this [long standing discussion about PX4 and autogyro](https://discuss.px4.io/t/auto-g2-gyrocopter-with-px4-autopilot/9942).

Special care should be taken to [Adding a new airframe group](https://dev.px4.io/master/en/airframes/adding_a_new_frame.html#adding-a-new-airframe-group) section during the pull-request creation.

Partial tasks resulting from the documentation are:

- [x] Create a Config File
- [x] Prepare the Mixer File (two axis rotor head)
- [x] Adding a New Airframe Group
    - [x] Add the svg image for the group into documentation repos
    - [x] Add a mapping between the new group name and image filename
    - [x] Update QGroundControl:

kaklik, 2020-01-28:
Merged https://github.com/PX4/Firmware/pull/14015

Closed 2020-01-28.

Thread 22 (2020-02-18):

Překreslit držák zadního podvozkového kolečka

kaklik, 2020-02-18:
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

https://hobbyking.com/en_us/duraflytm-auto-g2-gyrocopter-821mm-replacement-tail-wheel.html?wrh_pdp=7

kaklik, 2020-02-19:
Vytištěný model je vyslicovaný hodně dutě a neobsahuje otvor pro čepičku ukončující drát kolečka.

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

Tato čepička je v originálním dílu v úrovni trubky, aby nepřekážela výškovce.

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

kaklik, 2020-02-19:
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

roman-dvorak, 2020-02-22:
Kostku drážku je potřeba o 3 mm zkátit. Dále by bylo vhodné trošku prodloužit část do tyče a zvětšit o trochu průměr o 0.2mm.

Closed 2020-04-25.

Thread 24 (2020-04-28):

Doplnění dokumentace na webu PX4

kaklik, 2020-04-28:
Zde by bylo vhodné vytvořit novou kategorii "Autogyro" a přepsat do ní popis konstrukce:
https://docs.px4.io/master/en/airframes/

Některé části lze převzít odsud:
https://discuss.px4.io/t/auto-g2-gyrocopter-with-px4-autopilot/9942

kaklik, 2020-05-20:
Duplicitní issue.

Closed 2020-05-20.

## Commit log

2019-03-13 New file with measured model dimensions and printing size constants.
    [parameters.scad]
2019-03-13 pridani prvniho dilu od @Alsa-Tucnak
    [111_1001.scad]
2019-03-14 Dily 2 a 3 na rotorovou hlavu
    [111_1002.scad, 111_1003.scad]
2019-03-14 uprava rozmeru dilu, vytvoreni sestavy
    [111_1001.scad, 111_1003.scad, 111_1101.scad]
2019-03-14 Start work on rotor plate.
    [888_1001.scad, parameters.scad]
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2019-03-15 Move files to src directory and adding makefile.
    [111_1001.scad, 111_1001.stl, 111_1002.scad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]
2019-03-15 Design of 3blade rotor plate.
    [888_1001.scad, 888_1001.stl, parameters.scad]
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2019-03-18 Fix of wrong path to shared parameters.
    [111_1002.scad]
2019-03-18 Change configuration to two blade rotor.
    [111_1003b.scad, parameters.scad]
2019-03-18 Resize of rotor shaft to M3 screw.
    [111_1004.scad, 888_1001.scad]
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2019-03-20 FIX #5 slightly move the blade holes away from rotor shaft.
    [888_1001.scad]
2019-03-20 FIX #4 added even or odd blade number check.
    [111_1004.scad]
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2019-03-20 Improve printing tolerances.
    [111_1006.stl, 111_1102.stl, parameters.scad]
2019-03-20 uprava dilu pro rotorovou hlavu
    [111_1001.scad, 111_1002.scad, 111_1003.scad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]
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2019-03-21 Posun dilu 1003 tak, aby odpovidal puvodni pozici rotorove hlavy
    [111_1001.scad, 111_1003.scad, 111_1101.scad]
2019-03-21 Uprava dilu pro vetsi volnost v ose roll
    [111_1001.scad, 111_1003.scad, parameters.scad]
2019-03-22 Pokus o zkraceni sroubu pro tahla a symetrizaci pak.
    [111_1001.stl, 111_1003.scad, 111_1003.stl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]
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2019-03-22 Resize of rod distances for better fit of ball joints.
    [111_1003.scad]
2019-03-22 Rendering of printing files.
    [111_1002.stl, 111_1003.stl, 111_1101.stl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]
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2019-03-27 Uprava rozmeru dilu podle doporuceni Dobiase.
    [111_1003.scad, 111_1003.stl, 111_1101.scad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]
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2019-03-27 Rendering models with two variant of rotor lever.
    [111_1002.stl, 111_1003.scad, 111_1003_15.stl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]
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2019-03-29 Increase thickness of rotor plate. Improve optimal configuration of rotor head angles.
    [111_1003.scad, 111_1003.stl, 888_1001.scad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]
2019-03-29 uprava rozmeru podle puvodni rotorove hlavy
    [111_1003.scad, 111_1003_10.stl, 111_1003_13.stl]
2019-04-03 uprava rozmeru loziska a jejich vzdalenosti
    [parameters.scad]
2019-04-03 pridani zapustini matek do rotorove hlavy
    [111_1001.scad, 111_1001.stl]
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2019-04-03 Zmena parametru 'tloustka loziska na 4mm', Delka osy na zarovnana na vnejsi strany lozisek
    [111_1003.scad, 111_1003.stl, 111_1003_10.stl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]
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2019-04-05 Adding new rotor nut mounting part. Resolved #6
    [888_1002.scad, 888_1002.stl, parameters.scad]
2019-04-07 Pridani mostu na spodni strani dilu nad lozisko, zvetsena dira mezi lozisky.
    [111_1003.scad, parameters.scad]
2019-04-11 Increase thickness of side walls #1 Rendering models to print.
    [111_1001.scad, 111_1001.stl, 111_1003.stl]
2019-04-11 Removing hull to increase fragility of rotor part. Fixed #1
    [111_1003.scad, 111_1003.stl]
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2019-04-24 FIX #7 rotor blade thickness
    [888_1009.scad, parameters.scad]
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2019-04-26 Fix blade thickness.
    [print_plate_1009_shapeA.scad, print_plate_1009_shapeA.stl, print_plate_1009_shapeB.scad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]
2019-05-06 Printable rotor blade for Auto-G2, renamed print_plates, new parameters
    [111_1009.scad, 111_1009.stl, 111_1102.scad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]
2019-05-06 Nove rozdeleni rotoru na casti, Uprava parametru, zmena polohy vyztuh a der pro pripevneni.
    [111_1009.scad, 111_1009.stl, parameters.scad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]
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2019-05-06 Uprava tloustky pripevnovaciho dilu, prumer diry na jadro rotoru.
    [111_1009.scad, parameters.scad]
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2019-05-12 Upraveny dil rotoru a vytvorena mesi verze rotoru.
    [111_1009.scad, 111_1009.stl, 111_1009_small.stl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]
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2019-05-17 New testing rotor holder created. FIX #14
    [888_1003.scad]
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2019-05-17 FIX removing middlecut.
    [888_1003.scad, 888_1003.stl]
2019-05-24 Improved tightness of M2 screw holes. #13
    [111_1001.stl, 111_1003.stl, 111_1004.stl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]
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2019-06-10 Změna tiskové sestavy - obsahuje díly na dva tištěné listy zároveň zrcadlově otočené.
    [111_1009_parts.scad]
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2019-06-11 Úprava výšky sloupků, které drží servo, a zvěšení posunu držáku.
    [888_1010.scad]
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2019-06-12 renderovani modelu - oprava vysky dilu pro vypousteni
    [111_1002.stl, 111_1007.stl, 111_1009.stl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]
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2019-06-27 #11, print_plate nemá jeden pár zrcadlený ale pouze otočený okolo osy, ůprava parametrů, tenčí stěna, renderování.
    [111_1009.scad, 111_1009.stl, 111_1009_parts.scad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]
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2019-06-27 Uprava rozmeru del v castech plackach rotorove hlavy - parametr na velikost sroubu.
    [111_1005.scad, 111_1006.scad, 111_1006.stl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]
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2019-07-01 Upravena vzdalenost der ve sloupcich na 28 mm, cely dil je o trochu zkracen a spodni stena je o 0.5 mm tlustsi #15
    [888_1010.scad]
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2019-07-03 #17 doplneny diry, ktere umozni lepsi utrzeni listu
    [888_1001.scad]
2019-07-03 #17 vytvoreni sady desticek o ruznem prumeru vykousnuti
    [print_plate_888_1001_2,5.scad, print_plate_888_1001_3,5.scad, print_plate_888_1001_3.scad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]
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2019-08-09 Presunuti tiskove sestavy listu mezi tiskove sestavy. Vytvoreni tiskove sestavy pro male dilky rotoru Vygenerovany modely.
    [111_1009_parts.scad, print_plate_888_1001.scad, print_plate_888_1011.stl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]
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2019-08-09 Zvetšení tloušťky stěny listu na minimální tisknutelnou hodnotu. #11
    [parameters.scad]
2019-08-09 Oprava tloušťky stěn tak, aby byla vytisknutelná celá konstrukce listu.
    [parameters.scad]
2019-08-09 Posunutí dílů tak, aby spodní plochy ležící na tiskové podložce byly ve jedné rovině.
    [111_1004.scad, 111_1008.scad, print_plate_rotor_parts.stl]
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2019-12-19 Autogyro blade balancer design files moved to separate repository.
    https://github.com/ThunderFly-aerospace/blade_balancer
    [888_1009.scad, print_plate_888_1009_base.scad, print_plate_888_1009_cradle.scad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]
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2020-02-14 Uprava podlozek k rotorovym listum, Oprava sestavy rotoru
    [111_1005.scad, 111_1102.scad, parameters.scad]
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2020-02-17 revert master
    [111_1001.stl, 111_1002.amf, 111_1002.stl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]
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
